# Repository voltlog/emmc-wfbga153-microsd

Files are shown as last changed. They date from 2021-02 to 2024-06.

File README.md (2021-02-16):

# eMMC WFBGA153 to microSD card adapter PCB
This adapter can be used for data recovery purposes by soldering a WFBGA eMMC chip and connecting to a standard microSD card reader for read/write operations or if you would like to build an inexpensive storage device using cheap memory chips obtained from Ebay/Aliexpress or salvaged from other devices. Image below shows the adapter assembled with a Toshiba 4GB eMMC chip.

### What else do you need?
Besides this custom designed PCB you will need a couple of bypass capacitors (0.1-1uF 10V or above in 0603 package) and the eMMC memory chip. eMMC chips in WFBGA153 package are available from every big distributor but if you would like to try your luck with some inexpensive options, check out [this link.](https://voltlog.com/y/pg8ny)

Alternatively you can order this PCB adapter from my [Tindie store](https://www.tindie.com/products/voltlog/emmc-wfbga153-to-microsd-card-adapter-set-of-2/).

More info about this project in [Voltlog #351](https://youtu.be/pFo1xvBqbqs).

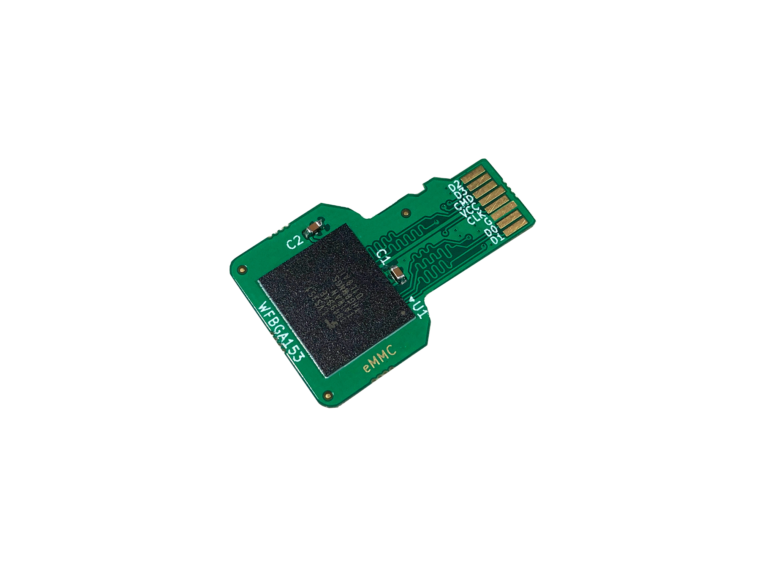
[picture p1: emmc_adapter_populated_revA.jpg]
Image of the assembled module


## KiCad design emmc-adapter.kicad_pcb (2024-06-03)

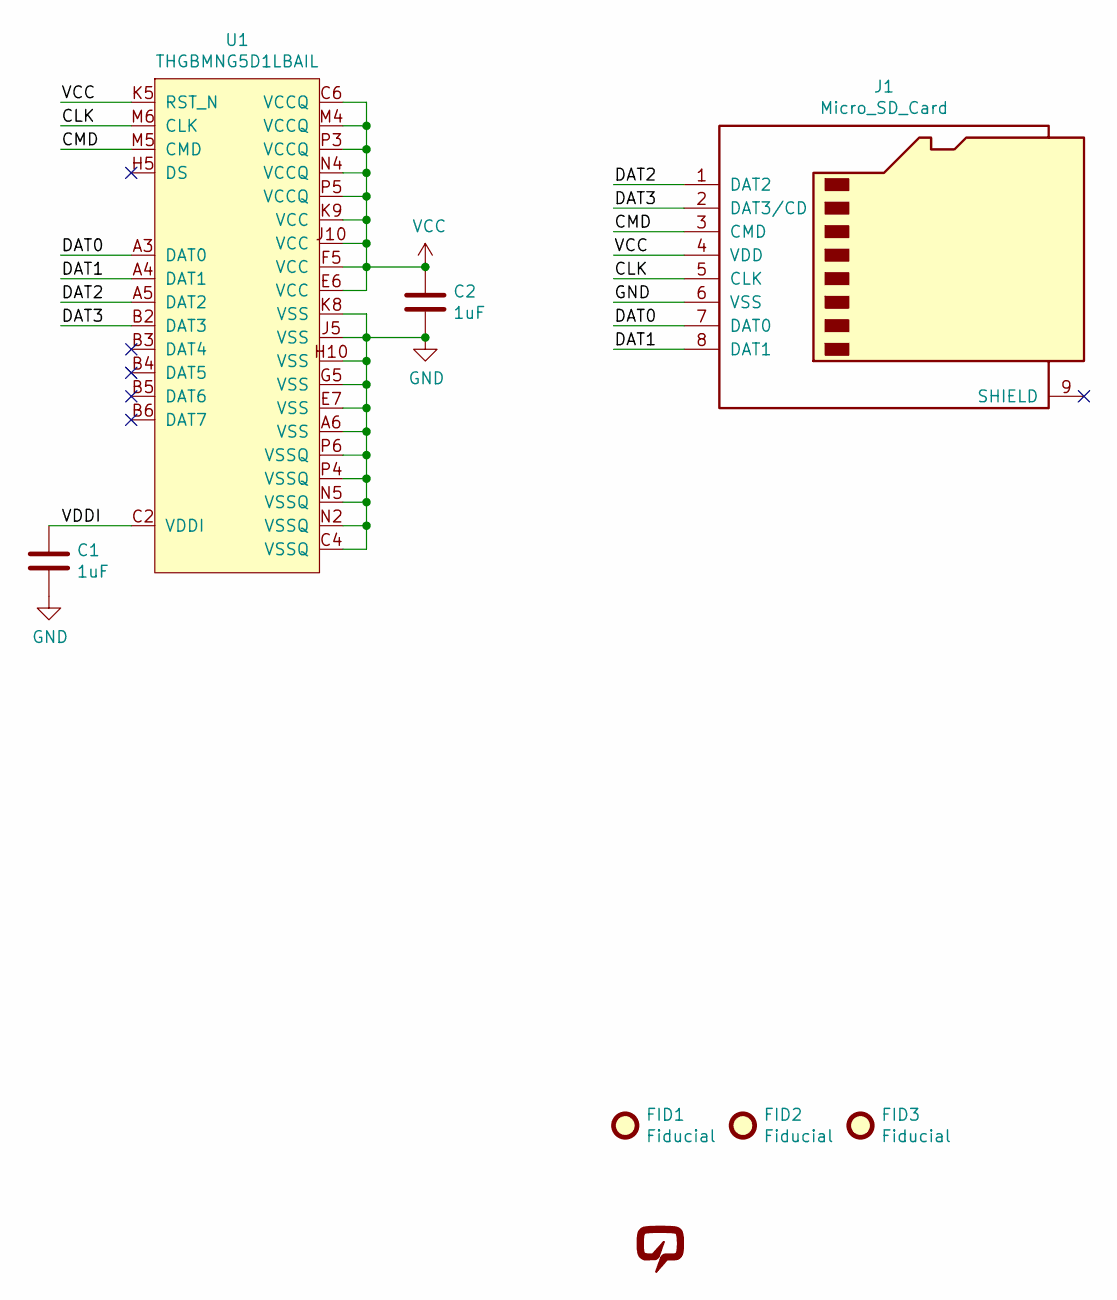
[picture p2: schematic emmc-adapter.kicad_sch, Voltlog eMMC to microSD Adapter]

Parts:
C1, C2: 1uF; C_0603_1608Metric
FID1, FID2, FID3: Fiducial; Fiducial_0.5mm_Mask1mm
J1: Micro_SD_Card; microSD_card
U1: THGBMNG5D1LBAIL; WFBGA153
V1: VOLTLOG_LOGO; voltlog_mask_3mm

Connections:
/CLK: J1.5 (CLK), U1.M6 (CLK)
/CMD: J1.3 (CMD), U1.M5 (CMD)
/DAT0: J1.7 (DAT0), U1.A3 (DAT0)
/DAT1: J1.8 (DAT1), U1.A4 (DAT1)
/DAT2: J1.1 (DAT2), U1.A5 (DAT2)
/DAT3: J1.2 (DAT3/CD), U1.B2 (DAT3)
/VDDI: C1.1, U1.C2 (VDDI)
GND: C1.2, C2.2, J1.6 (VSS), U1.A6 (VSS), U1.C4 (VSSQ), U1.E7 (VSS), U1.G5 (VSS), U1.H10 (VSS), U1.J5 (VSS), U1.K8 (VSS), U1.N2 (VSSQ), U1.N5 (VSSQ), U1.P4 (VSSQ), U1.P6 (VSSQ)
VCC: C2.1, J1.4 (VDD), U1.C6 (VCCQ), U1.E6 (VCC), U1.F5 (VCC), U1.J10 (VCC), U1.K5 (RST_N), U1.K9 (VCC), U1.M4 (VCCQ), U1.N4 (VCCQ), U1.P3 (VCCQ), U1.P5 (VCCQ)

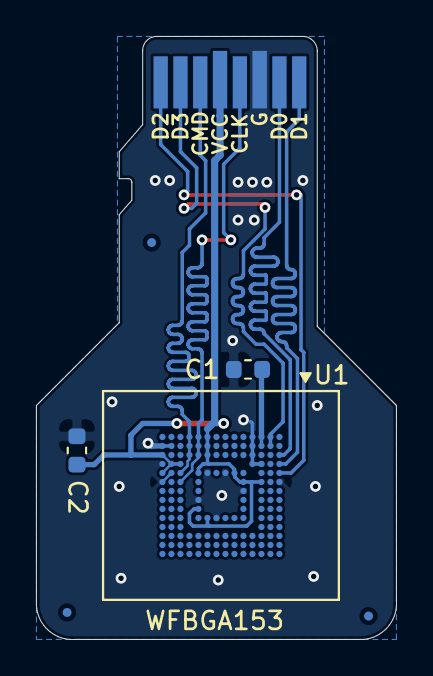
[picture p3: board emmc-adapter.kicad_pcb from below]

Board: 2 copper layers, 20.0 x 33.5 mm, 8 parts (7 on the bottom side), 9 nets.

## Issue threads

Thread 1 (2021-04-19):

Missing layout files

antonok-edm, 2021-04-19:
This KiCad project appears to be missing its PCB layout (the `.kicad_pcb` file). It's hard to tell if that's accidental or intentional, but I figured it would be good to mention considering how few open source examples of WFBGA153 eMMC board layouts there are on the internet.

voltlog, 2021-04-19:
Added missing file.

Closed 2021-04-19.

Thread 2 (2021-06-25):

missing library file

shawaj, 2021-06-25:
the schematic doesn't load fully due to missing library symbol for the emmc chip

voltlog, 2021-06-30:
I'll have to clean-up and publish the voltlog kicad library at some point but for this project I think I remember using a publicly availably WFBGA153 library which I don't have on my computer anymore.

Closed 2021-06-30.

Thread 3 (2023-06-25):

How did you design the microSD footprint and align with PCB layout?

marcosscriven, 2023-06-25:
Hi

I'm trying to create a PCB that plugs into a microSD slot, as yours does (but for a different purpose).

I opened the project in KiCad and can see in the schematic you've laid out the pads, but I'm wondering how you made sure those pads were in the right spot compared to the PCB outline, which in this case is very important.

voltlog, 2023-06-26:
Hi,
This is not an issue with the project.

Closed 2023-06-26.

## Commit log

2021-02-16 Initial commit, published project.
    [emmc-adapter-B_Cu.gbr, emmc-adapter-B_Mask.gbr, emmc-adapter-B_Paste.gbr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]
2021-04-19 Added missing .kicad_pcb file
    [emmc-adapter.kicad_pcb]
2024-06-03 Project updated to Kicad v8
    [emmc-adapter-B_Cu.gbr, emmc-adapter-B_Mask.gbr, emmc-adapter-B_Paste.gbr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]
